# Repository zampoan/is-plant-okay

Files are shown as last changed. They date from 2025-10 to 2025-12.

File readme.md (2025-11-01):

# Is-Plant-Okay 🌱?
## Concept
A solar-powered sensor node that uses a low-power camera and a tiny on-board ML model to detect early signs of plant disease. It will be mounted on a stake and its purpose is to continuously watch the same plant or section of crop bed. 

It will periodically take a picture every 4 hours. When it sees trouble, and will send a compact alert packet over LoRa to a base station. The farmer will receive a notification and can inspect or treat the plant before disease spreads.

Dataset to be trained on: https://www.kaggle.com/datasets/vipoooool/new-plant-diseases-dataset

ML model: https://www.nature.com/articles/s41598-025-06452-5

## Hardware
- 🧠 MCU: Arduino Nano 33 BLE Sense Rev2 
- 🔋 LiIon: 7.4 2000mAh
- ☀️ Solar power cells: 0.5W Solar Panel 55x70
- 📷 Camera: CAMERA-OV7670
- 🌡️ Temperature sensor: Arduino Nano 33 BLE Sense Rev2 (onboard HS3003)
- 🌡️ Humidity sensor: Arduino Nano 33 BLE Sense Rev2 (onboard HS3003)
- ~~🌡️ Soil moisture sensor: (Premi um option: RS485)~~
- 🖵 Screen: GRAPHIC DISPLAY TFT RGB 0.96"
- 📡 LoRa: SX1278 RA-02 (Premium option:RYLR998)
- ~~💡 Light Sensor: TSL2591~~
- ~~⚡ UV Sensor: VEML6075~~

## Software
- KiCad 9.0: Schematic diagram drawing & PCB design
- Fusion 360: Case design

# BOM:
| Hardware | Price ($USD) | QTY| Link |
| :---: | :---: | :--: | :--: |
| Arduino Nano 33 BLE Sense Rev 2 | 38.70 | 1 | https://www.digikey.com.au/en/products/detail/arduino/ABX00069/16891607?s=N4IgTCBcDaIIICEAaAGNA2AnCAugXyA
| 0.5W Solar Panel 55x70 | 6.07 | 2 | https://www.digikey.com.au/en/products/detail/seeed-technology-co-ltd/313070004/5488049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
| CAMERA-OV7670 | 10.25 | 1 | https://www.digikey.com.au/en/products/detail/olimex-ltd/CAMERA-OV7670/21662189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
| (Camera Alternative) Mini 2MP SPI Camera Module | 25.99 | 1 | https://core-electronics.com.au/mini-2mp-spi-camera-module-for-raspberry-pi-pico.html
| GRAPHIC DISPLAY TFT RGB 0.96" | 12.65| 1 | https://www.digikey.com.au/en/products/detail/adafruit-industries-llc/3533/7386265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
| LORA BREAKOUT BOARD WITH ANTENNA (SX1278) | 4.12 | 2 |https://www.digikey.com.au/en/products/detail/ai-thinker/RA-01S-KIT/16688834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
| (Lora alternative) WIO-E5 MINI DEV BRD STM32WLE5JC | 21.90 | 1 | https://www.digikey.com.au/en/products/detail/seeed-technology-co-ltd/113990939/13926228
| 18650 BATTERY PROTECTION MODULE | 3.9 | 1 | https://www.digikey.com.au/en/products/detail/dfrobot/FIT0869/15997370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
| BATT HOLDER 18650 2 CELL PC PIN | 5.16 | 1 | https://www.digikey.com.au/en/products/detail/mpd-memory-protection-devices/BK-18650-PC4/2330513
| SPI RTC | 27.5 | 1 | https://www.digikey.com.au/en/products/detail/sparkfun-electronics/10160/5318743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

## Inspiration
https://blog.arduino.cc/2020/06/24/machine-vision-with-low-cost-camera-modules/
https://cdn-learn.adafruit.com/downloads/pdf/adafruit-mini-tft-0-dot-96-inch-180x60-breakout.pdf
https://files.seeedstudio.com/products/317990687/res/LoRa-E5%20module%20datasheet_V1.0.pdf

# Project Timeline
## Stage 0: Project Conceptualization
Stage 0 focuses on identifying the key skills to develop for this project. My goal was to deepen my understanding of wireless communication and explore how to integrate machine learning into embedded devices. I was particularly interested in how these technologies could support farmers and forest rangers in monitoring crops and plants across large, diverse environment. My goal was to make it as cheap as possible and require little human interaction once placed.

## Stage 1a: Development board stage
Stage 1a involves selecting different components to interface with each other. The most important element was the microcontroller, and I choose the Arduino Nano 33 BLE Sense V2 for its built in sensor capabilities, community support and access to TF-lite as an edge-ml solution.

The next was selecting a camera, I needed a camera that I could use off the shelf quickly for developing. Originally HM0360-MWA-00FP963 was selected, but I found it difficult to find a dev board for it. So the OV7670 was selected instead.

Similiar to the camera, SX1278 RA-02 module was selected because a dev board was available, and the DS3234 was chosen because SPI is the common protocol that is being used.

## Stage 1b: Developing the model
The model that is being used is based of the paper: [AI and IoT-powered edge device optimized for crop pest and disease detection](https://www.nature.com/articles/s41598-025-06452-5) and is called Tiny-LiteNet. It was chosen because of its use case matched  and identifiable metrics used to train and test the model. 

The model is made from scratch and is trained on a different dataset and uses a pretrained MobileNetv2 model as a teacher model. Tiny-LiteNet utilises six squeeze-and-excitation (SE) depthwise blocks to enhance feature representation, reduce compute cost and improve accuracy combined. The size of this model is 1.2Mb.

Tiny-LiteNet architecture:
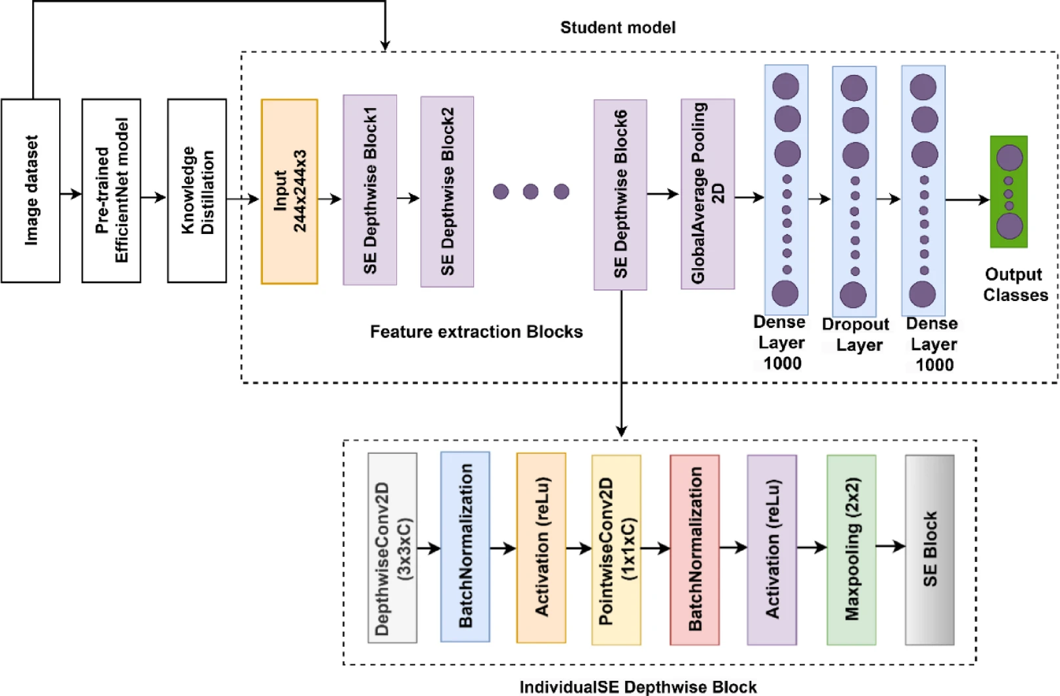
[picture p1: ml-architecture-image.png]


## Stage 2a: PCB design

## Stage 2b: CAD design

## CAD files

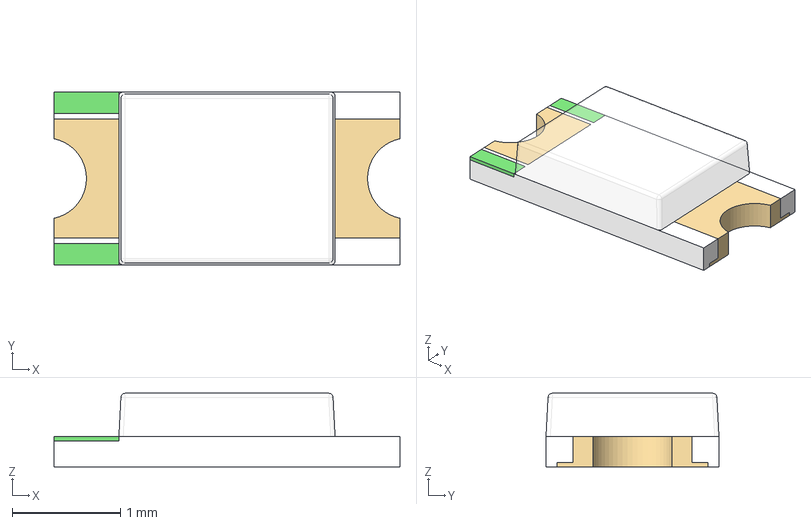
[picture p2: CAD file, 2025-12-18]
ELECTRICAL/is-plant-okay/KICAD_PROJECT_LIBRARY/150120GS75000_/WL-SMCW_1206.step
3.20 x 1.60 x 0.68 mm
marking x 2
housing
cover
base x 2

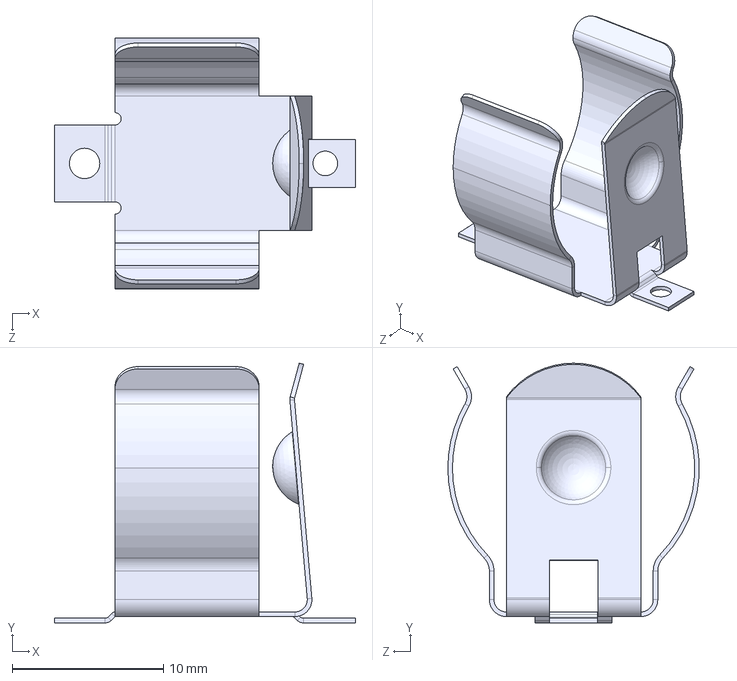
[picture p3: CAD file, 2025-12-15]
ELECTRICAL/is-plant-okay/KICAD_PROJECT_LIBRARY/254TR-2/254TR.step
19.9 x 17.2 x 16.6 mm

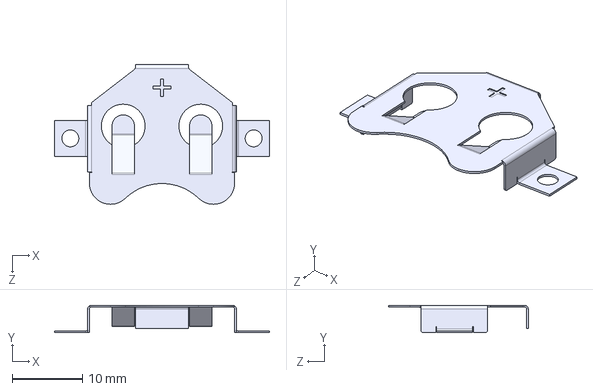
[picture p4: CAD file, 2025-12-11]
ELECTRICAL/is-plant-okay/KICAD_PROJECT_LIBRARY/BAT_HLD_003_SMT/BAT-HLD-003-SMT.step
30.5 x 3.90 x 19.8 mm

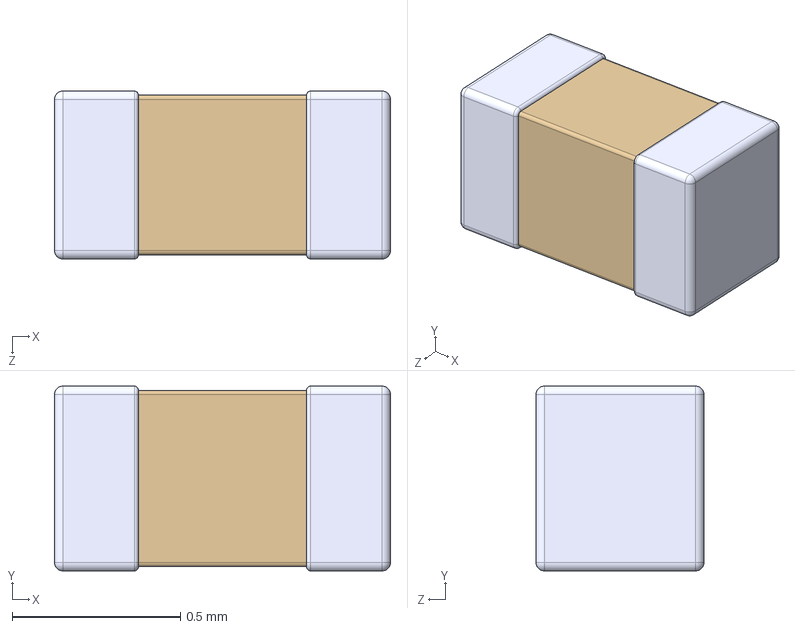
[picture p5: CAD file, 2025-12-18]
ELECTRICAL/is-plant-okay/KICAD_PROJECT_LIBRARY/CL05B104KO5NNNC/CL05B104KO5NNNC.step
1.00 x 0.55 x 0.5 mm

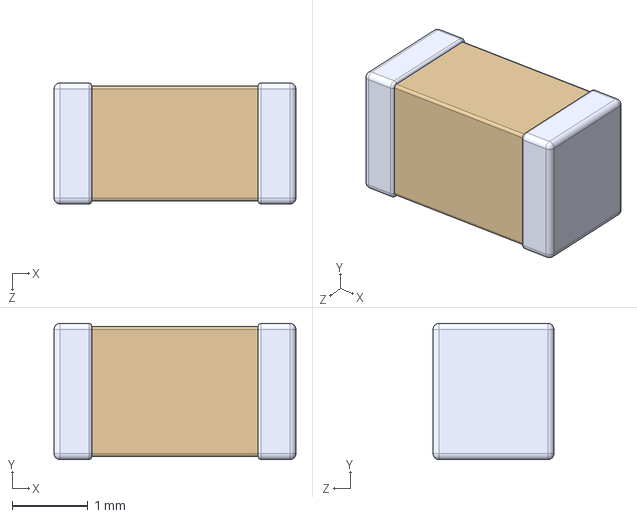
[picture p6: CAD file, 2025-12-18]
ELECTRICAL/is-plant-okay/KICAD_PROJECT_LIBRARY/CL31B105KBHNNNE/CL31B105KBHNNNE.step
3.20 x 1.80 x 1.60 mm

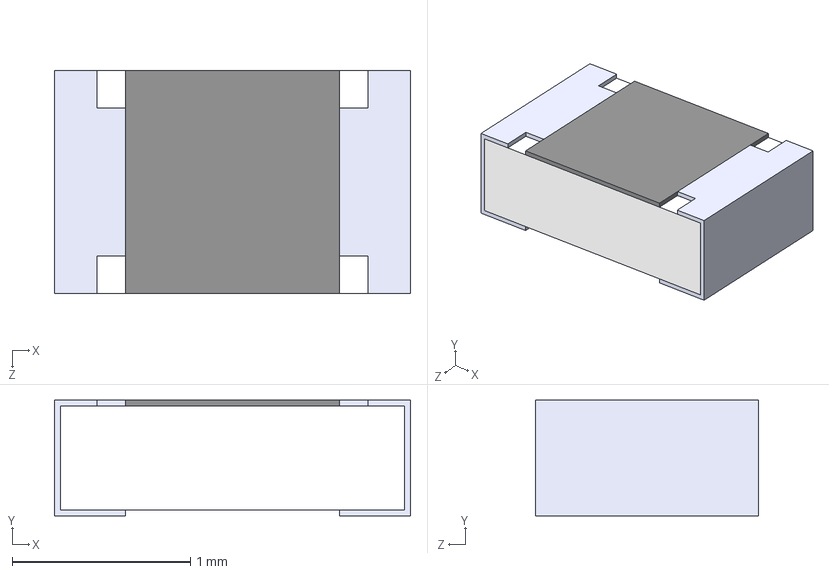
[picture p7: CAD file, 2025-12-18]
ELECTRICAL/is-plant-okay/KICAD_PROJECT_LIBRARY/CRGCQ0805J470R/CRGCQ0805J470R.step
2.00 x 0.65 x 1.25 mm

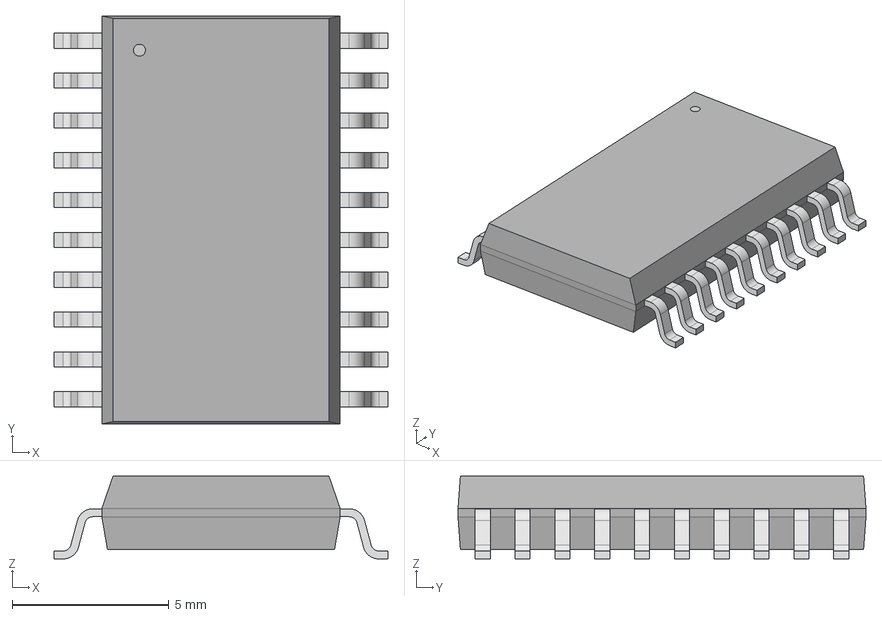
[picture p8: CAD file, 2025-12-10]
ELECTRICAL/is-plant-okay/KICAD_PROJECT_LIBRARY/DS3234S_T_R/21-0042O_W20H2_MXM.step
10.6 x 13.0 x 2.64 mm

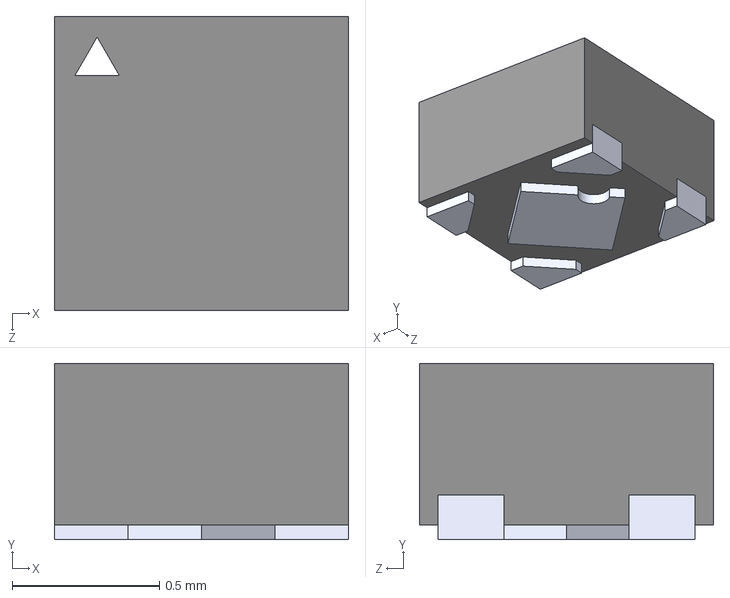
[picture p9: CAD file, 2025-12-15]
ELECTRICAL/is-plant-okay/KICAD_PROJECT_LIBRARY/MIC5365_3_3YMT_TZ/MIC5365-3.3YMT-TZ.step
1.00 x 0.6 x 1.00 mm

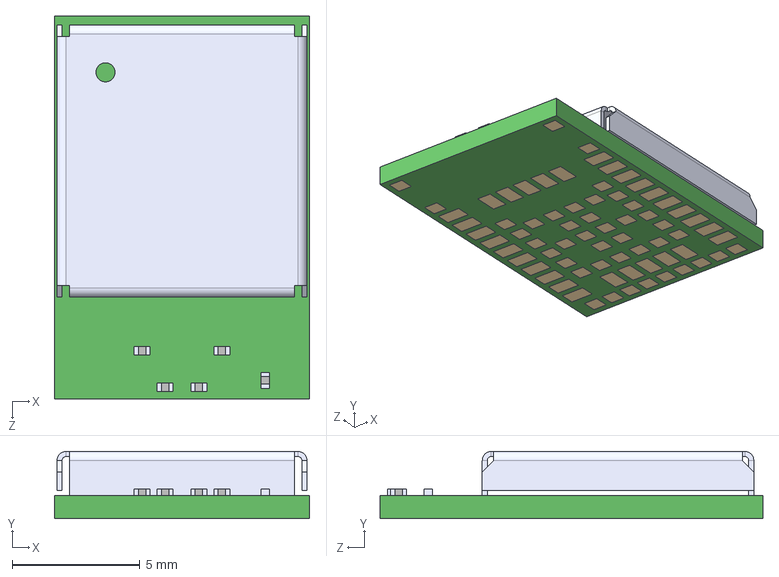
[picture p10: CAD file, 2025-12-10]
ELECTRICAL/is-plant-okay/KICAD_PROJECT_LIBRARY/NINA_B306_00B/NINA-B306-00B.step
10.0 x 2.63 x 15.0 mm

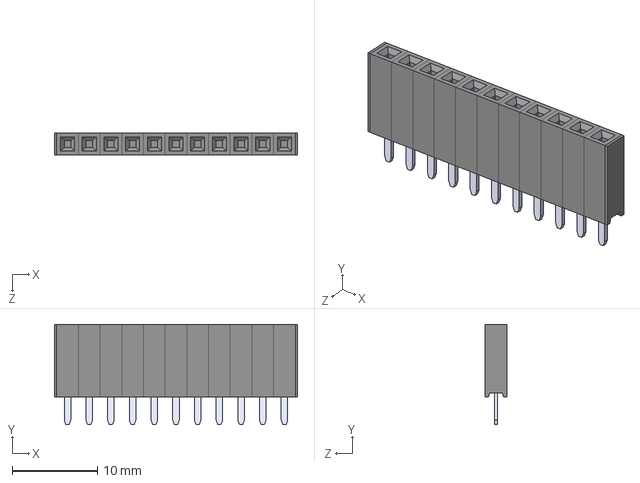
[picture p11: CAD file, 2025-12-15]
ELECTRICAL/is-plant-okay/KICAD_PROJECT_LIBRARY/PPTC111LFBN-RC/PPTC111LFBN-RC.STEP
28.4 x 11.7 x 2.54 mm
PPPC021LFBN-RC_C11
Pin - Tin x 11

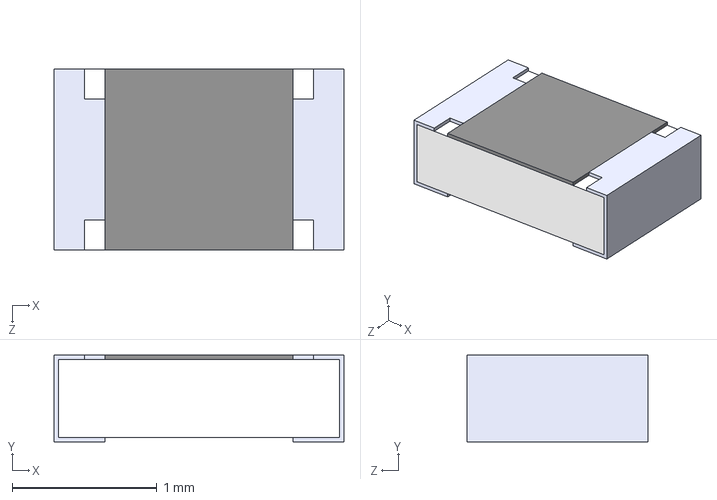
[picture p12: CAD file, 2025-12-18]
ELECTRICAL/is-plant-okay/KICAD_PROJECT_LIBRARY/RC0805FR_7W10KL/RC0805FR-7W10KL.step
2.00 x 0.6 x 1.25 mm

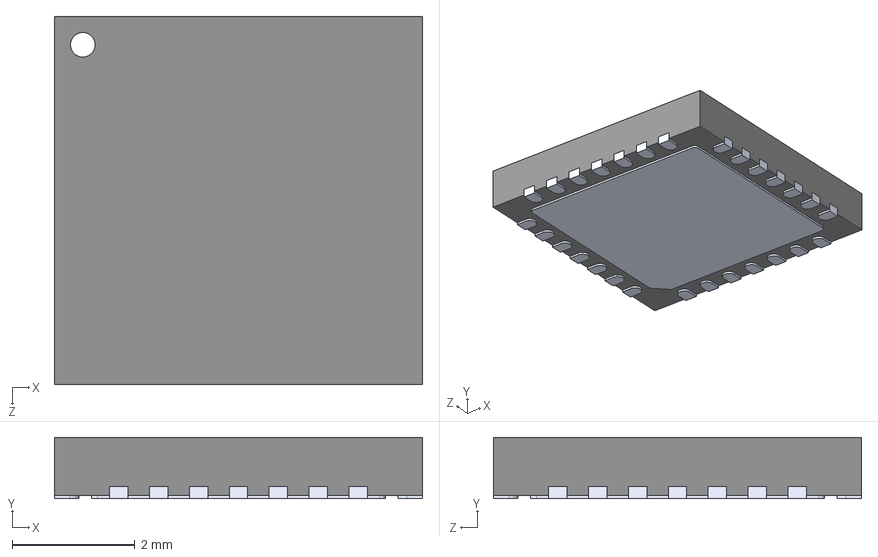
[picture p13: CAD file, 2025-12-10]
ELECTRICAL/is-plant-okay/KICAD_PROJECT_LIBRARY/SX1276IMLTRT/SX1276IMLTRT.step
6.00 x 1.00 x 6.00 mm

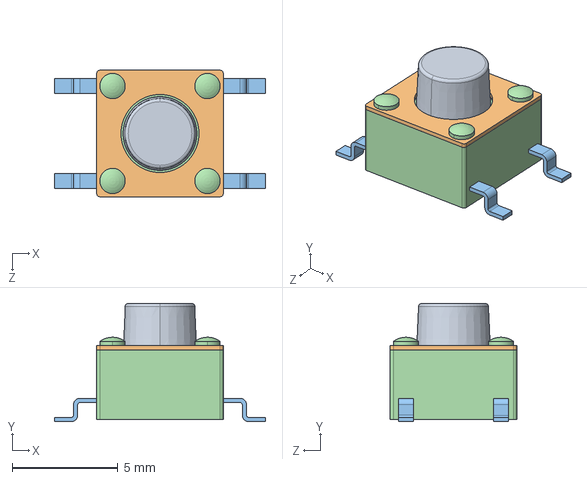
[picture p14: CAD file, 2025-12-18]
ELECTRICAL/is-plant-okay/KICAD_PROJECT_LIBRARY/TS04_66_55_BK_260_SMT/TS04-66-55-BK-260-SMT.STEP
10.0 x 5.60 x 6.00 mm

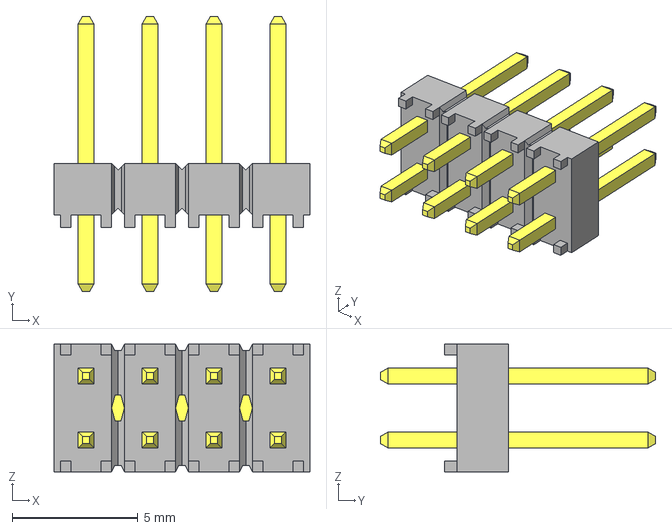
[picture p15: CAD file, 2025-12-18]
ELECTRICAL/is-plant-okay/KICAD_PROJECT_LIBRARY/TSW_104_07_F_D/TSW-104-07-F-D.stp
10.2 x 10.9 x 5.08 mm
TSW-104-07-F-D_body
T-1S6-07-TSW-1-07-4-D

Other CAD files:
ELECTRICAL/is-plant-okay/KICAD_PROJECT_LIBRARY/RC0805JR_075K1L/RC0805JR-075K1L.step
ELECTRICAL/is-plant-okay/KICAD_PROJECT_LIBRARY/UJ20_C_H_G_SMT_5_P16_TR/UJ20-C-H-G-SMT-5-P16-TR.step
ELECTRICAL/is-plant-okay/KICAD_PROJECT_LIBRARY/USB4085_GF_A/USB4085-GF-A.STEP
ELECTRICAL/is-plant-okay/KICAD_PROJECT_LIBRARY/USBLC6_2SC6-2/USBLC6-2SC6.step
ELECTRICAL/is-plant-okay/KICAD_PROJECT_LIBRARY/10129381_918001BLF/10129381-918001BLF.step
ELECTRICAL/is-plant-okay/KICAD_PROJECT_LIBRARY/BQ24650RVAT/BQ24650RVAT.step
ELECTRICAL/is-plant-okay/KICAD_PROJECT_LIBRARY/BQ7791504PW/BQ7791504PW.step
ELECTRICAL/is-plant-okay/KICAD_PROJECT_LIBRARY/MCP73871_2CCI_ML/MCP73871-2CCI_ML.step
ELECTRICAL/is-plant-okay/KICAD_PROJECT_LIBRARY/Wio-SX1262 Module Kicad Library/Wio-SX1262 file.step
ELECTRICAL/is-plant-okay/KICAD_PROJECT_LIBRARY/ZOR_25_B_52_0R/RES_ZOR25_6P3X2P3_YAG.step

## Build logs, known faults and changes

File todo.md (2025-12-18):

# Todo list
## Stage 1a
 - Put together hardware
 - Code software to interface w/ hardware
## Stage 1b
- Test and deploy model
- Build pipeline?
## Stage 2a
- Make Rev 1 of PCB
Complete schematics for the following:
    - MCU
    - ~~DISPLAY_TFT~~
    - ~~RTC_DS3234~~
    - ~~CAMERA~~    
    - ~~LoRA~~
    - ~~USB_C~~
    - ~~MCP78371~~

- Check if GPIO is default High impedance from the registers

Find out if below is possible:
| Goal | Best Option | 
| :---: | :---: |
| Want to run Arduino sketches | Flash Arduino Nano BLE bootloader |
| Want to run Python scripts | Use Adafruit UF2 bootloader + CircuitPython| 
| Want full control / Zephyr / SDK | Use Nordic’s SDK + J-Link |
| Want both Arduino + MicroPython flexibility| Use Adafruit UF2 bootloader, supports both|

- learn to write over the bootloader, flash from scratch

## Stage 2b
- Design model housing

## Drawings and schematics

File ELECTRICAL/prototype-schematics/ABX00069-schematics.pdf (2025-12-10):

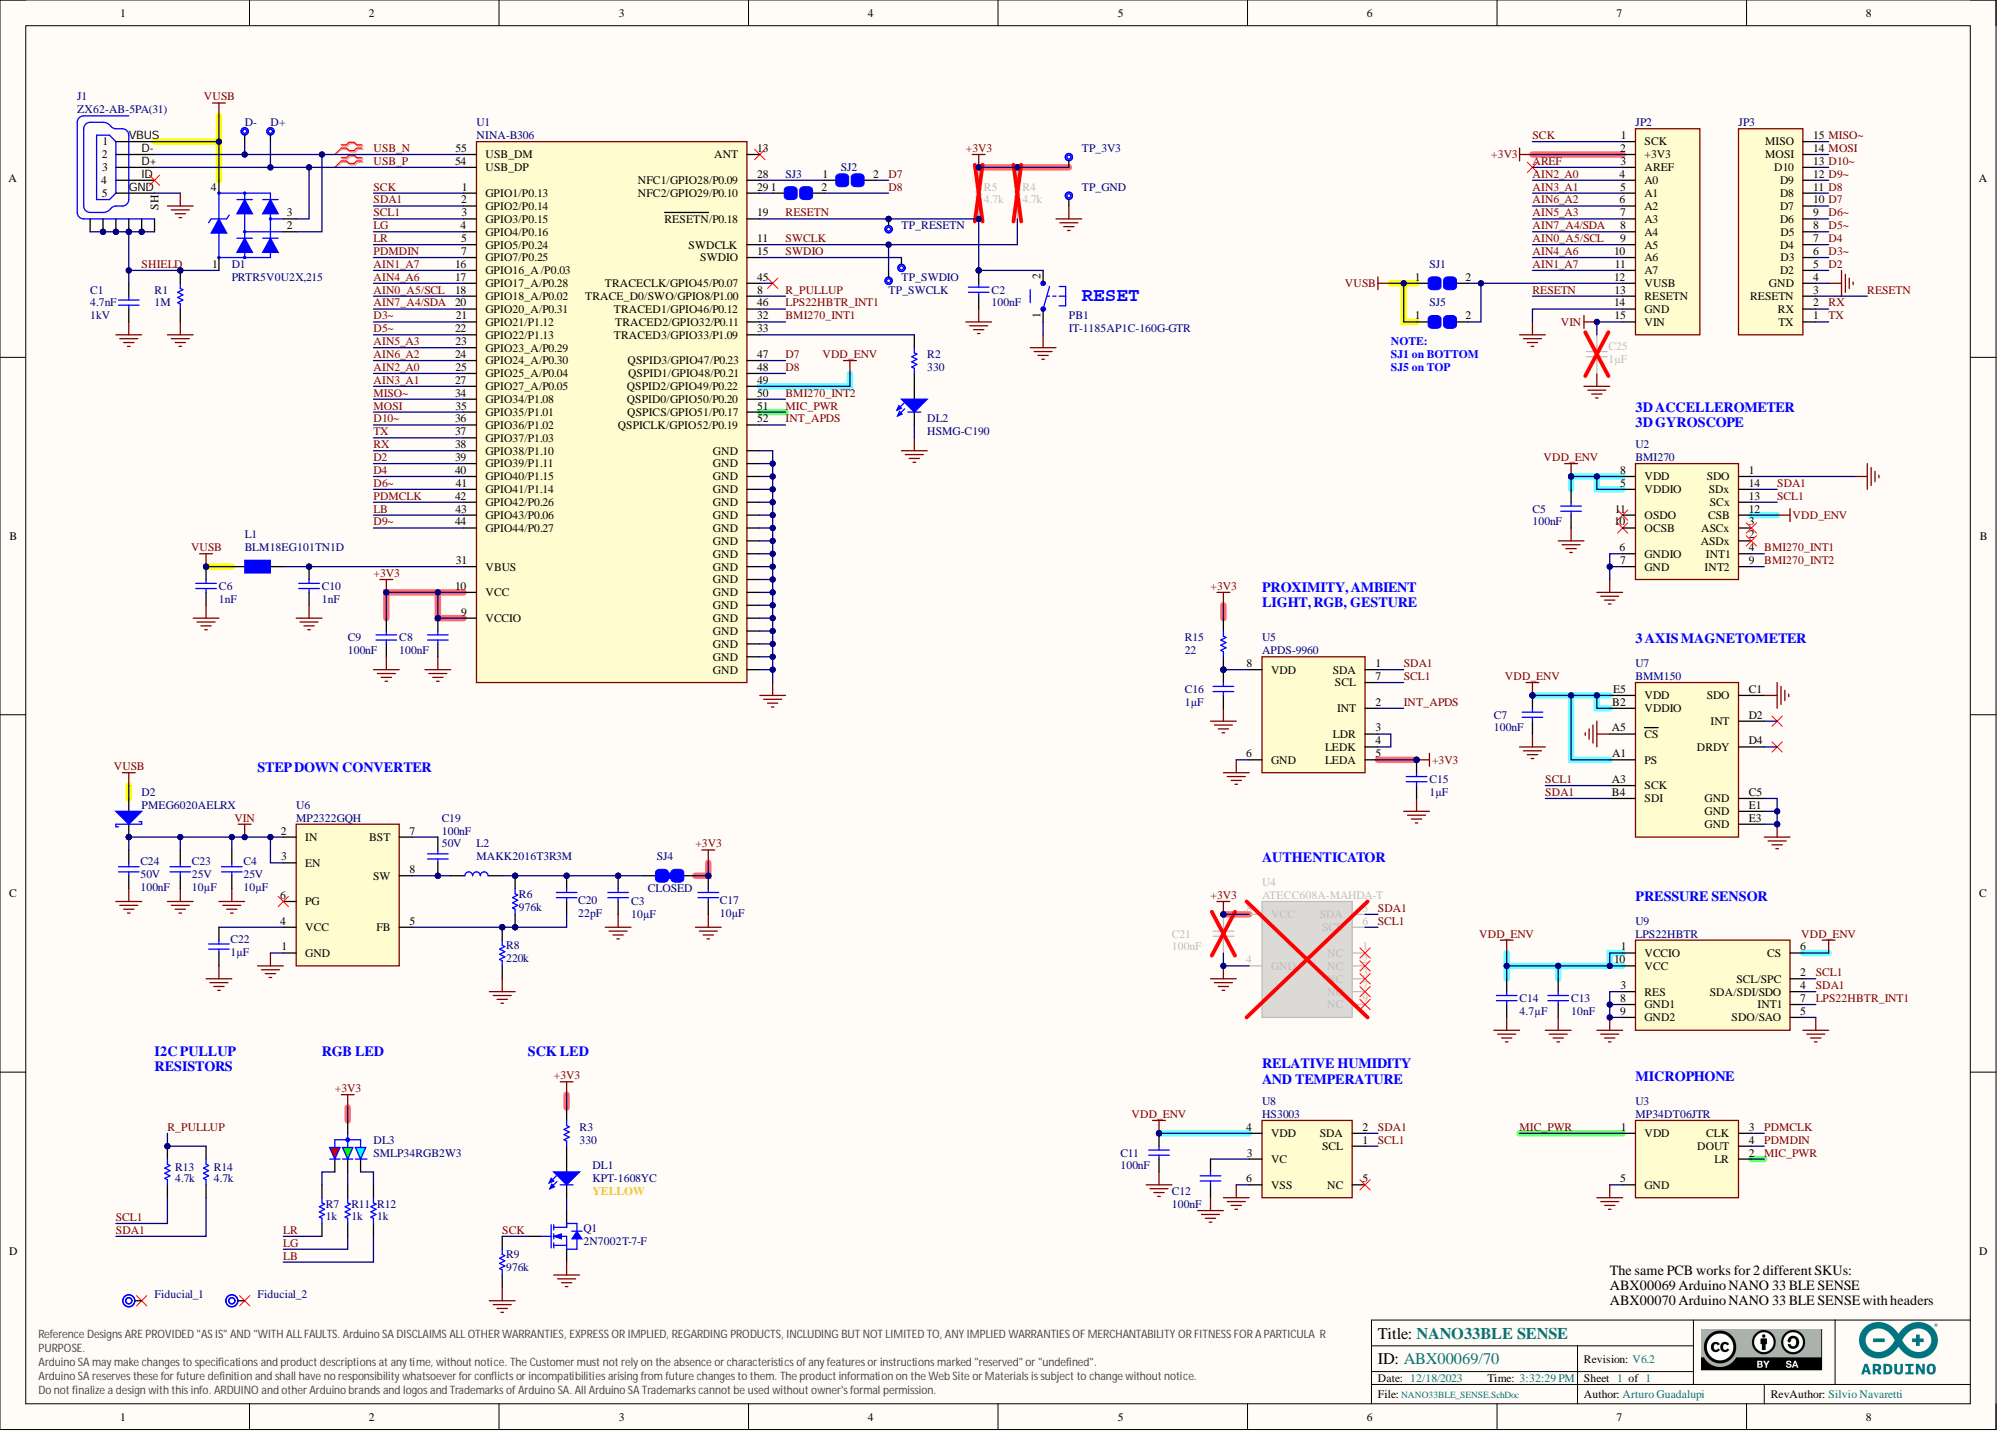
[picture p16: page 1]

E 1
E 3

Reference Designs ARE PROVI
PURPOSE.
Arduino SA may ma
Arduino SA reserves these for future definition and shall have no responsibility whatsoever for conflicts or incompatibiliti

DED "AS IS" AND "WITH ALL FAULTS. Arduino SA DISCLAIMS ALL OTHER WARRANTIES, EXPRESS OR IMPLIED, REGARDING PRODUCTS, INCLUDING BUT NOT LIMITED TO, ANY IMPLIED WARRANTIES OF MERCHANTABI

ke changes to specifi

tions and product descriptions at a

ce. The Customer must not rely on the absence or cha

ny features or instructions ma

rked "reserved" or "undefined".

rising from future changes to them. The product informa

tion on the Web Site or Materials is subject to change without noti

Do not finalize a design with this info. ARDUINO and other Arduino brands and logos and Tradema

rks of Arduino SA. All Arduino SA Tradema

rks cannot be used without owner's formal permission.

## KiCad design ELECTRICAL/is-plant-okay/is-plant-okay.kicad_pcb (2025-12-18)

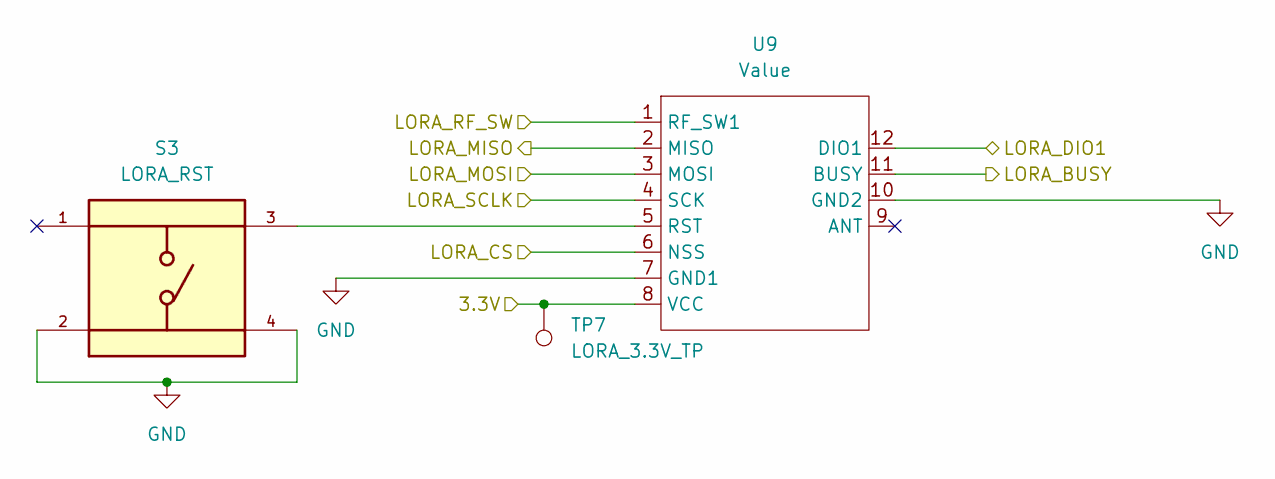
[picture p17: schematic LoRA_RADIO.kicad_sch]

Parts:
S3: LORA_RST; SW_TS04-66-55-BK-260-SMT; MFG PART # TS04-66-55-BK-260-SMT
TP7: LORA_3.3V_TP; TestPoint_Keystone_5000-5004_Miniature
U9: Value; Wio-SX1262 PCB Package; MFG PART # 114993390

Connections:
/3.3V: TP7.1, U9.8 (VCC); also elsewhere on the board
/LORA_BUSY: U9.11 (BUSY); also elsewhere on the board
/LORA_CS: U9.6 (NSS); also elsewhere on the board
/LORA_DIO1: U9.12 (DIO1); also elsewhere on the board
/LORA_MISO: U9.2 (MISO); also elsewhere on the board
/LORA_MOSI: U9.3 (MOSI); also elsewhere on the board
/LORA_RF_SW: U9.1 (RF_SW1); also elsewhere on the board
/LORA_SCLK: U9.4 (SCK); also elsewhere on the board
GND: S3.2, S3.4, U9.7 (GND1), U9.10 (GND2); also elsewhere on the board
unnamed: S3.3, U9.5 (RST)

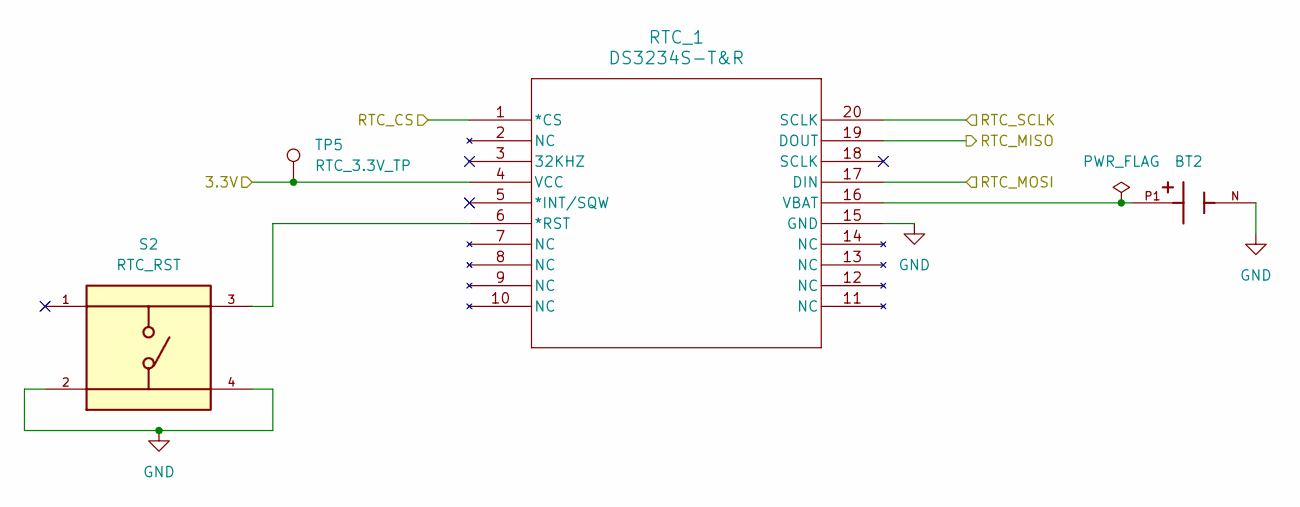
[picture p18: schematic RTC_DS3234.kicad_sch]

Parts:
BT2: BAT-HLD-003-SMT; BAT_BAT-HLD-003-SMT; MFG PART # BAT-HLD-003-SMT
RTC_1: DS3234S-T&R; 21-0042O_W20-H2_MXM-L; MFG PART # DS3234S#
S2: RTC_RST; SW_TS04-66-55-BK-260-SMT; MFG PART # TS04-66-55-BK-260-SMT
TP5: RTC_3.3V_TP; TestPoint_Keystone_5000-5004_Miniature

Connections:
/3.3V: RTC_1.4 (VCC), TP5.1; also elsewhere on the board
/LORA_MISO: RTC_1.19 (DOUT); also elsewhere on the board
/LORA_MOSI: RTC_1.17 (DIN); also elsewhere on the board
/LORA_SCLK: RTC_1.20 (SCLK); also elsewhere on the board
/RTC_CS: RTC_1.1 (*CS); also elsewhere on the board
GND: BT2.N, RTC_1.15 (GND), S2.2, S2.4; also elsewhere on the board
unnamed: RTC_1.6 (*RST), S2.3
unnamed: BT2.P1, RTC_1.16 (VBAT)

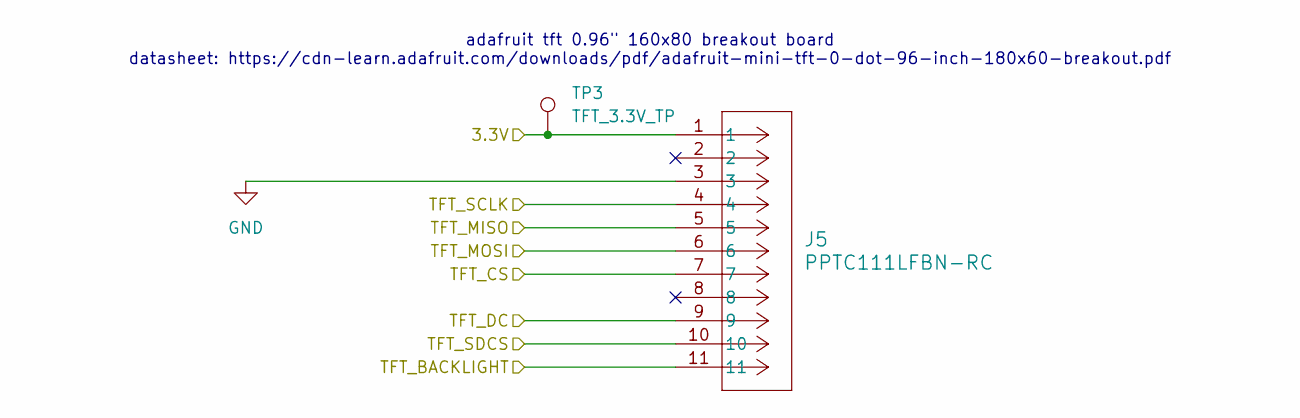
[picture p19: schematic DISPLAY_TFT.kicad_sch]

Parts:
J5: PPTC111LFBN-RC; CONN11_PPPN111_SUL; MFG PART # PPTC111LFBN-RC
TP3: TFT_3.3V_TP; TestPoint_Keystone_5000-5004_Miniature

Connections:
/3.3V: J5.1, TP3.1; also elsewhere on the board
/BACKLIGHT: J5.11; also elsewhere on the board
/LORA_MISO: J5.5; also elsewhere on the board
/LORA_MOSI: J5.6; also elsewhere on the board
/LORA_SCLK: J5.4; also elsewhere on the board
/TFT_CS: J5.7; also elsewhere on the board
/TFT_DC: J5.9; also elsewhere on the board
/TFT_SDCS: J5.10; also elsewhere on the board
GND: J5.3; also elsewhere on the board

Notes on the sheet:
adafruit tft 0.96" 160x80 breakout board datasheet: https://cdn-learn.adafruit.com/downloads/pdf/adafruit-mini-tft-0-dot-96-inch-180x60-breakout.pdf

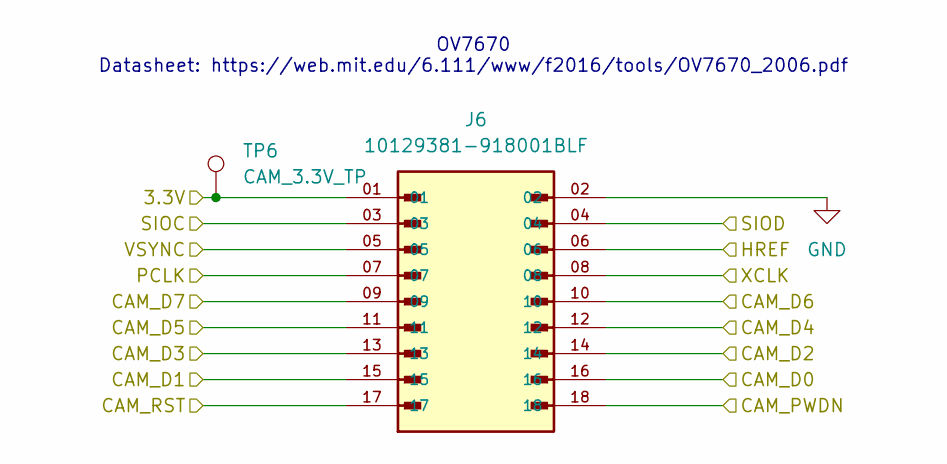
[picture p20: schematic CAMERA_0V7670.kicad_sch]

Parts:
J6: 10129381-918001BLF; AMPHENOL_10129381-918001BLF; MFG PART # 10129381-918001BLF
TP6: CAM_3.3V_TP; TestPoint_Keystone_5000-5004_Miniature

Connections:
/3.3V: J6.01, TP6.1; also elsewhere on the board
/CAM_D0: J6.16; also elsewhere on the board
/CAM_D1: J6.15; also elsewhere on the board
/CAM_D2: J6.14; also elsewhere on the board
/CAM_D3: J6.13; also elsewhere on the board
/CAM_D4: J6.12; also elsewhere on the board
/CAM_D5: J6.11; also elsewhere on the board
/CAM_D6: J6.10; also elsewhere on the board
/CAM_D7: J6.09; also elsewhere on the board
/CAM_PWDN: J6.18; also elsewhere on the board
/CAM_RST: J6.17; also elsewhere on the board
/HREF: J6.06; also elsewhere on the board
/PCLK: J6.07; also elsewhere on the board
/SIOC: J6.03; also elsewhere on the board
/SIOD: J6.04; also elsewhere on the board
/VSYNC: J6.05; also elsewhere on the board
/XCLK: J6.08; also elsewhere on the board
GND: J6.02; also elsewhere on the board

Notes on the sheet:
OV7670 Datasheet: https://web.mit.edu/6.111/www/f2016/tools/OV7670_2006.pdf

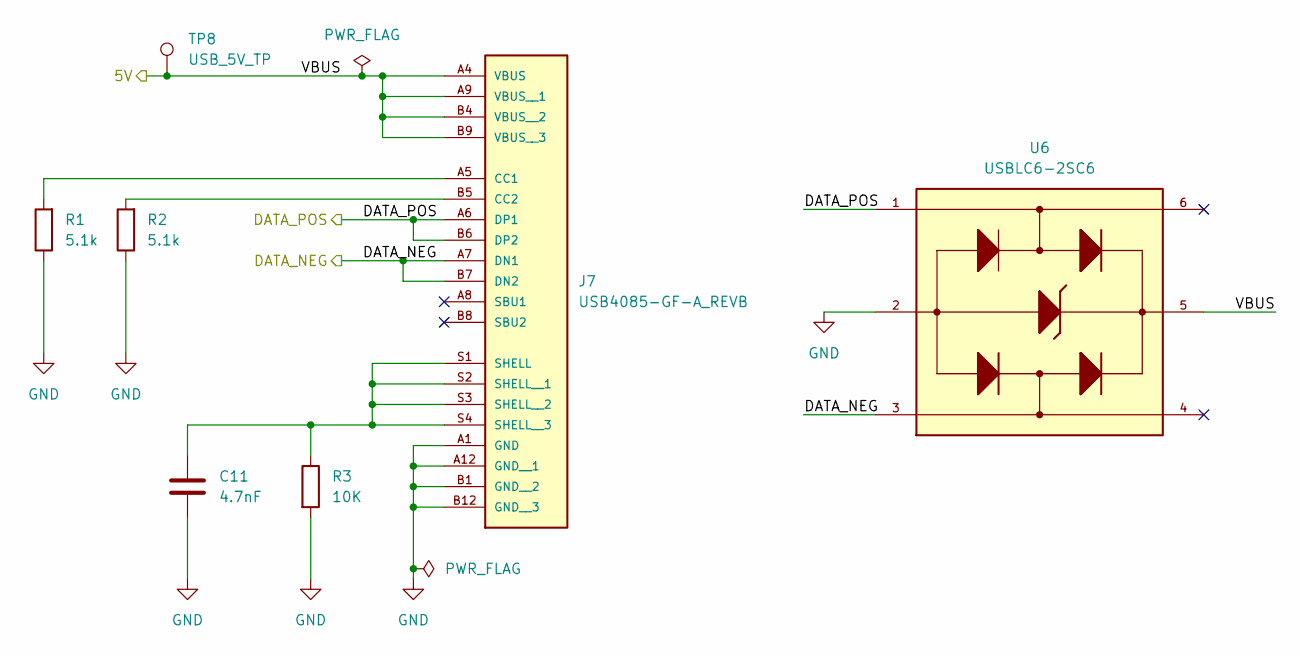
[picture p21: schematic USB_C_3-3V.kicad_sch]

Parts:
C11: 4.7nF; CAPC1005X55N; MFG PART # CL05B104KO5NNNC
J7: USB4085-GF-A_REVB; GCT_USB4085-GF-A_REVB; MFG PART # USB4085-GF-A
R1, R2: 5.1k; RC0805JR-075K1L; MFG PART # RC0805JR-075K1L
R3: 10K; RC0805FR-7W10KL; MFG PART # RC0805FR-7W10KL
TP8: USB_5V_TP; TestPoint_Keystone_5000-5004_Miniature
U6: USBLC6-2SC6; SOT95P280X145-6N; MFG PART # USBLC6-2SC6

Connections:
/5V: J7.A4 (VBUS), J7.A9 (VBUS__1), J7.B4 (VBUS__2), J7.B9 (VBUS__3), TP8.1, U6.5; also elsewhere on the board
/DATA_NEG: J7.A7 (DN1), J7.B7 (DN2), U6.3; also elsewhere on the board
/DATA_POS: J7.A6 (DP1), J7.B6 (DP2), U6.1; also elsewhere on the board
GND: C11.2, J7.A1 (GND), J7.A12 (GND__1), J7.B1 (GND__2), J7.B12 (GND__3), R1.1, R2.1, R3.2, U6.2; also elsewhere on the board
unnamed: J7.A5 (CC1), R1.2
unnamed: J7.B5 (CC2), R2.2
unnamed: C11.1, J7.S1 (SHELL), J7.S2 (SHELL__1), J7.S3 (SHELL__2), J7.S4 (SHELL__3), R3.1

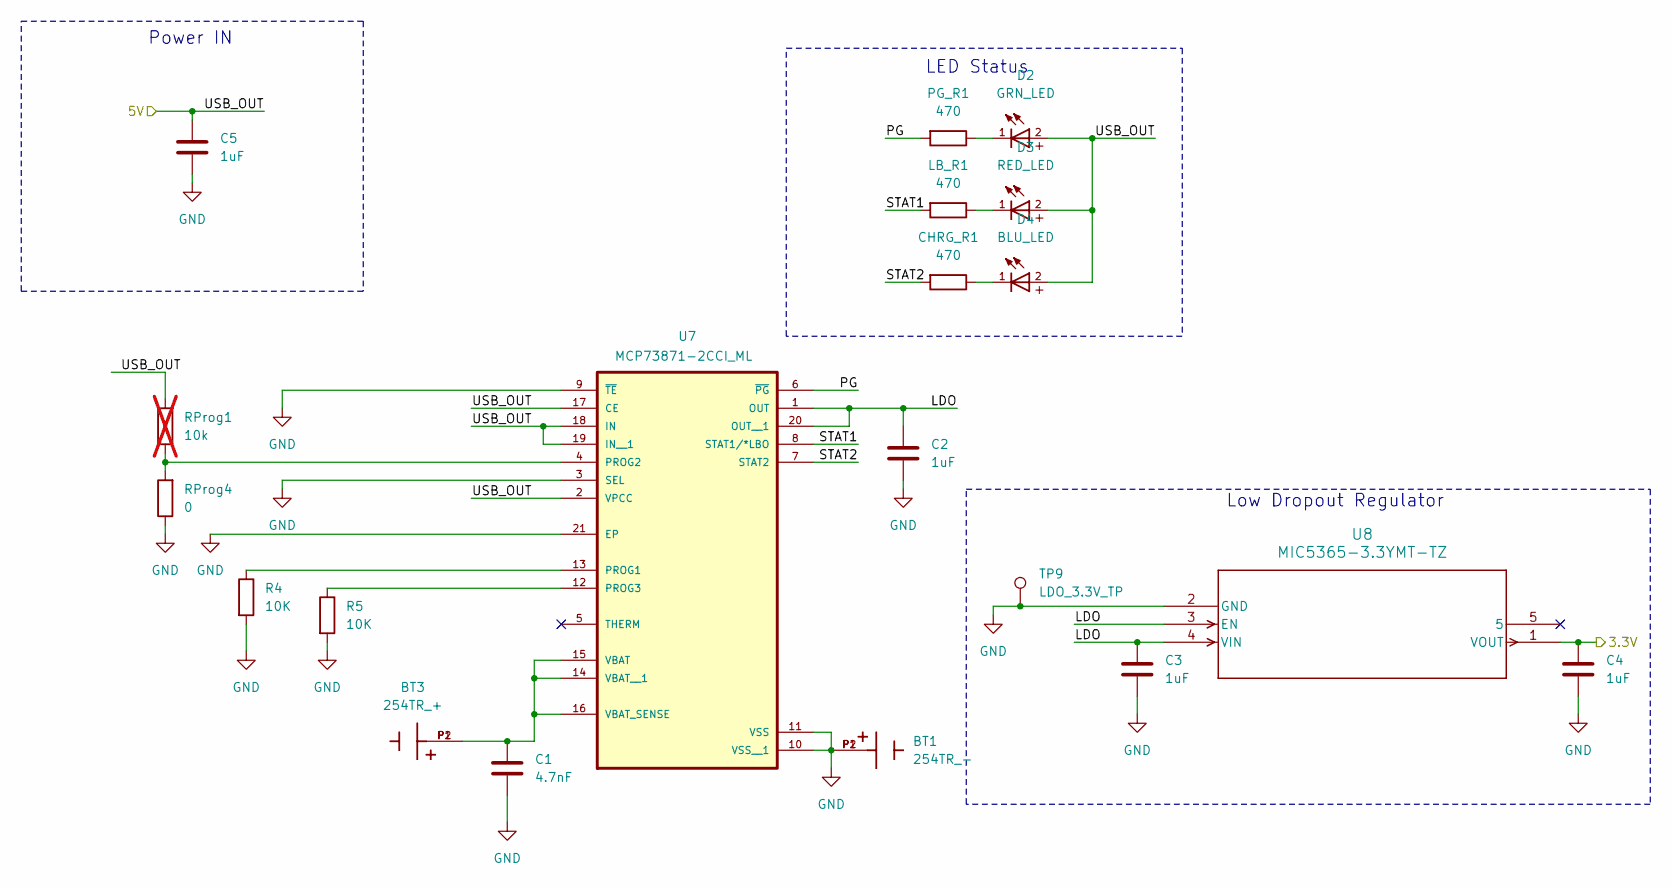
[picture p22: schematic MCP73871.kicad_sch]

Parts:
BT1: 254TR_-; BAT_254TR; MFG PART # 254TR
BT3: 254TR_+; BAT_254TR; MFG PART # 254TR
C1: 4.7nF; CAPC1005X55N; MFG PART # CL05B104KO5NNNC
C2, C3, C4, C5: 1uF; CAPC3216X180N; MFG PART # CL31B105KBHNNNE
CHRG_R1: 470; RESC2012X65N
D2: GRN_LED; 150120GS75000; MFG PART # 150120GS75000
D3: RED_LED; 150120GS75000; MFG PART # 150120RS75000
D4: BLU_LED; 150120GS75000; MFG PART # 150120BS75000
LB_R1: 470; RESC2012X65N
PG_R1: 470; RESC2012X65N
R4, R5: 10K; RC0805FR-7W10KL; MFG PART # RC0805FR-7W10KL
RProg1: 10k; RES_ZOR25_6P3X2P3_YAG; MFG PART # ZOR-25-B-52-0R; not fitted
RProg4: 0; RES_ZOR25_6P3X2P3_YAG; MFG PART # ZOR-25-B-52-0R
TP9: LDO_3.3V_TP; TestPoint_Keystone_5000-5004_Miniature
U7: MCP73871-2CCI_ML; QFN50P400X400X100-21N; MFG PART # MCP73871-2CCI/ML
U8: MIC5365-3.3YMT-TZ; TMLF-4_MCH; MFG PART # MIC5365-3.3YMT-TZ

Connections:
/3.3V: C4.1, U8.1 (VOUT); also elsewhere on the board
/5V: C5.1, D2.2, D3.2, D4.2, RProg1.2, U7.2 (VPCC), U7.17 (CE), U7.18 (IN), U7.19 (IN__1); also elsewhere on the board
/MCP73871/LDO: C2.1, C3.1, U7.1 (OUT), U7.20 (OUT__1), U8.3 (EN), U8.4 (VIN)
/MCP73871/PG: PG_R1.2, U7.6 (~PG)
/MCP73871/STAT1: LB_R1.2, U7.8 (STAT1/*LBO)
/MCP73871/STAT2: CHRG_R1.2, U7.7 (STAT2)
GND: BT1.P1, BT1.P2, C1.2, C2.2, C3.2, C4.2, C5.2, R4.2, R5.2, RProg4.1, TP9.1, U7.3 (SEL), U7.9 (~TE), U7.10 (VSS__1), U7.11 (VSS), U7.21 (EP), U8.2 (GND); also elsewhere on the board
unnamed: CHRG_R1.1, D4.1
unnamed: D2.1, PG_R1.1
unnamed: D3.1, LB_R1.1
unnamed: R4.1, U7.13 (PROG1)
unnamed: RProg1.1, RProg4.2, U7.4 (PROG2)
unnamed: R5.1, U7.12 (PROG3)
unnamed: BT3.P1, BT3.P2, C1.1, U7.14 (VBAT__1), U7.15 (VBAT), U7.16 (VBAT_SENSE)

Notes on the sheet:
Low Dropout Regulator
LED Status
Power IN

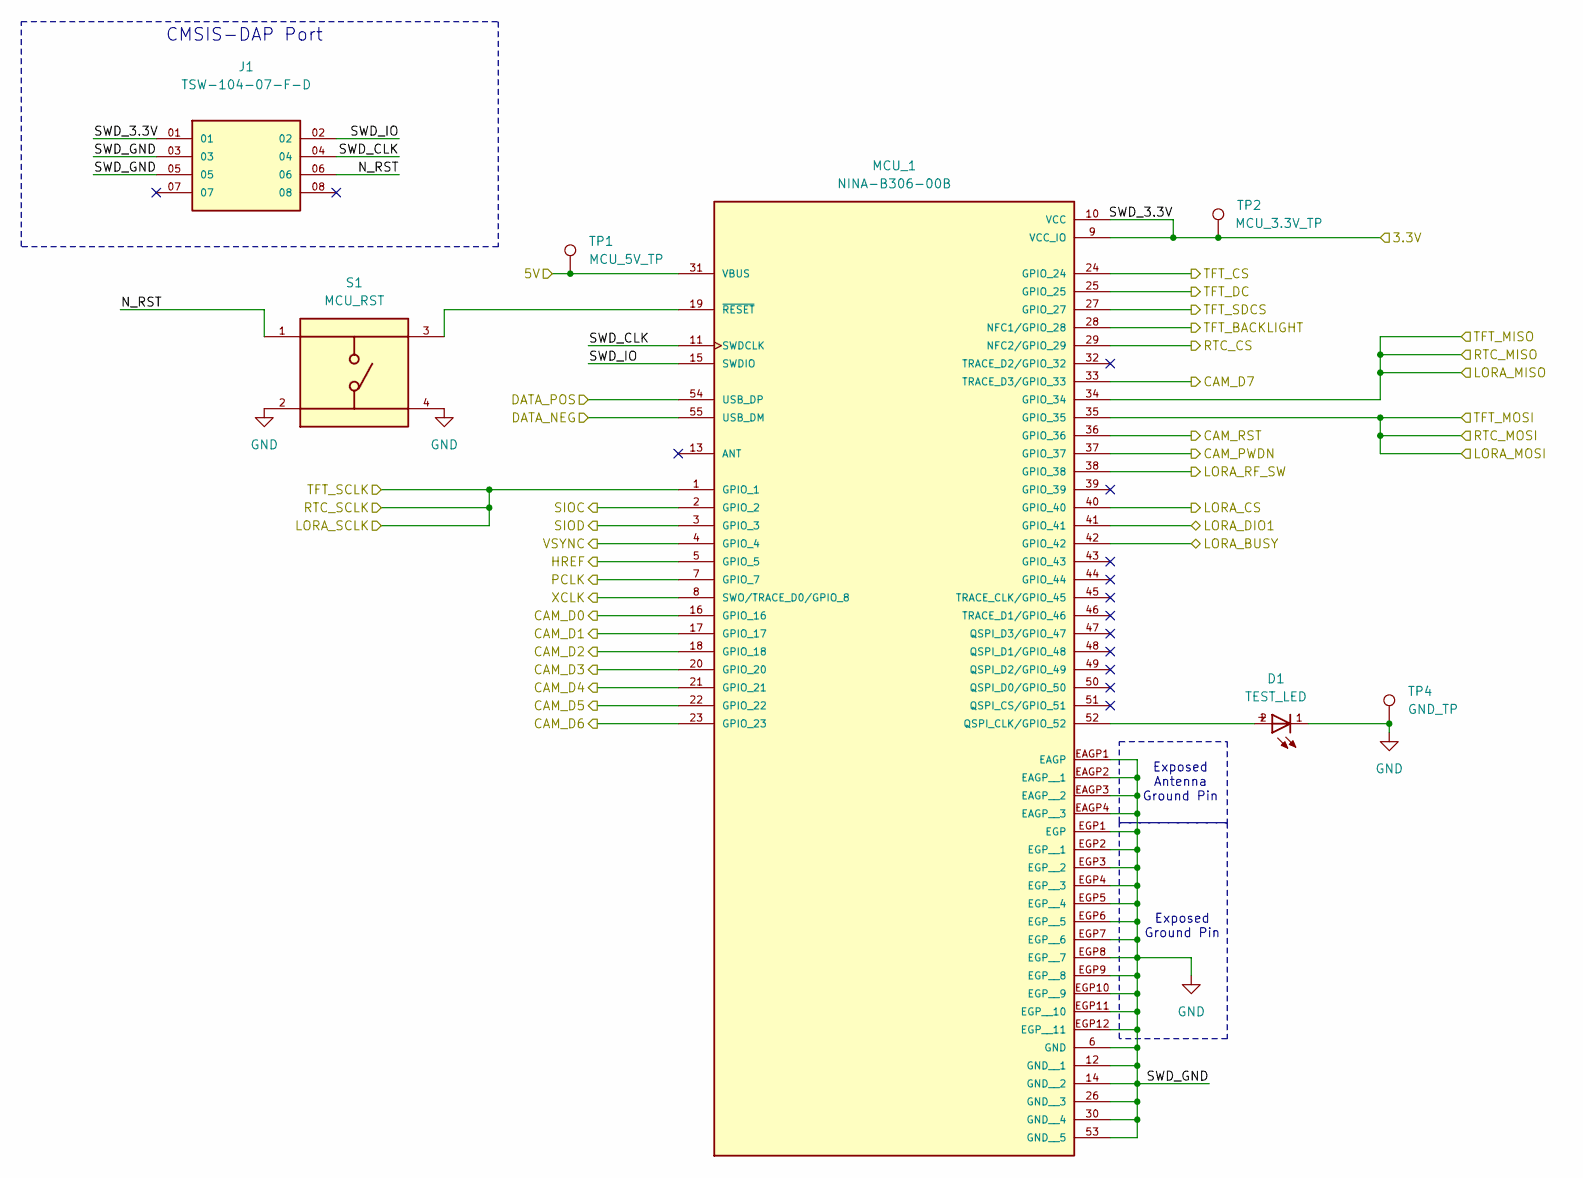
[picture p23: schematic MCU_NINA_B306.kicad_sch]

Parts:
D1: TEST_LED; 150120GS75000; MFG PART # 150120GS75000
J1: TSW-104-07-F-D; SAMTEC_TSW-104-07-F-D
MCU_1: NINA-B306-00B; XCVR_NINA-B306-00B; MFG PART # NINA-B306-01B
S1: MCU_RST; SW_TS04-66-55-BK-260-SMT; MFG PART # TS04-66-55-BK-260-SMT
TP1: MCU_5V_TP; TestPoint_Keystone_5000-5004_Miniature
TP2: MCU_3.3V_TP; TestPoint_Keystone_5000-5004_Miniature
TP4: GND_TP; TestPoint_Keystone_5000-5004_Miniature

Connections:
/3.3V: J1.01, MCU_1.9 (VCC_IO), MCU_1.10 (VCC), TP2.1; also elsewhere on the board
/5V: MCU_1.31 (VBUS), TP1.1; also elsewhere on the board
/BACKLIGHT: MCU_1.28 (NFC1/GPIO_28); also elsewhere on the board
/CAM_D0: MCU_1.16 (GPIO_16); also elsewhere on the board
/CAM_D1: MCU_1.17 (GPIO_17); also elsewhere on the board
/CAM_D2: MCU_1.18 (GPIO_18); also elsewhere on the board
/CAM_D3: MCU_1.20 (GPIO_20); also elsewhere on the board
/CAM_D4: MCU_1.21 (GPIO_21); also elsewhere on the board
/CAM_D5: MCU_1.22 (GPIO_22); also elsewhere on the board
/CAM_D6: MCU_1.23 (GPIO_23); also elsewhere on the board
/CAM_D7: MCU_1.33 (TRACE_D3/GPIO_33); also elsewhere on the board
/CAM_PWDN: MCU_1.37 (GPIO_37); also elsewhere on the board
/CAM_RST: MCU_1.36 (GPIO_36); also elsewhere on the board
/DATA_NEG: MCU_1.55 (USB_DM); also elsewhere on the board
/DATA_POS: MCU_1.54 (USB_DP); also elsewhere on the board
/HREF: MCU_1.5 (GPIO_5); also elsewhere on the board
/LORA_BUSY: MCU_1.42 (GPIO_42); also elsewhere on the board
/LORA_CS: MCU_1.40 (GPIO_40); also elsewhere on the board
/LORA_DIO1: MCU_1.41 (GPIO_41); also elsewhere on the board
/LORA_MISO: MCU_1.34 (GPIO_34); also elsewhere on the board
/LORA_MOSI: MCU_1.35 (GPIO_35); also elsewhere on the board
/LORA_RF_SW: MCU_1.38 (GPIO_38); also elsewhere on the board
/LORA_SCLK: MCU_1.1 (GPIO_1); also elsewhere on the board
/MCU_NINA_B306/N_RST: J1.06, S1.1
/MCU_NINA_B306/SWD_CLK: J1.04, MCU_1.11 (SWDCLK)
/MCU_NINA_B306/SWD_IO: J1.02, MCU_1.15 (SWDIO)
/PCLK: MCU_1.7 (GPIO_7); also elsewhere on the board
/RTC_CS: MCU_1.29 (NFC2/GPIO_29); also elsewhere on the board
/SIOC: MCU_1.2 (GPIO_2); also elsewhere on the board
/SIOD: MCU_1.3 (GPIO_3); also elsewhere on the board
/TFT_CS: MCU_1.24 (GPIO_24); also elsewhere on the board
/TFT_DC: MCU_1.25 (GPIO_25); also elsewhere on the board
/TFT_SDCS: MCU_1.27 (GPIO_27); also elsewhere on the board
/VSYNC: MCU_1.4 (GPIO_4); also elsewhere on the board
/XCLK: MCU_1.8 (SWO/TRACE_D0/GPIO_8); also elsewhere on the board
GND: D1.1, J1.03, J1.05, MCU_1.6 (GND), MCU_1.12 (GND__1), MCU_1.14 (GND__2), MCU_1.26 (GND__3), MCU_1.30 (GND__4), MCU_1.53 (GND__5), MCU_1.EAGP1 (EAGP), MCU_1.EAGP2 (EAGP__1), MCU_1.EAGP3 (EAGP__2), MCU_1.EAGP4 (EAGP__3), MCU_1.EGP1 (EGP), MCU_1.EGP2 (EGP__1), MCU_1.EGP3 (EGP__2), MCU_1.EGP4 (EGP__3), MCU_1.EGP5 (EGP__4), MCU_1.EGP6 (EGP__5), MCU_1.EGP7 (EGP__6), MCU_1.EGP8 (EGP__7), MCU_1.EGP9 (EGP__8), MCU_1.EGP10 (EGP__9), MCU_1.EGP11 (EGP__10), MCU_1.EGP12 (EGP__11), S1.2, S1.4, TP4.1; also elsewhere on the board
unnamed: D1.2, MCU_1.52 (QSPI_CLK/GPIO_52)
unnamed: MCU_1.19 (~RESET), S1.3

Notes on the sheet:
Exposed Antenna Ground Pin
Exposed Ground Pin
CMSIS-DAP Port

Board: 2 copper layers, 43 parts (0 on the bottom side), 54 nets, no tracks yet.

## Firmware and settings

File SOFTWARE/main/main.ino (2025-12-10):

/*
    Before starting, install following libraries:
        - adafruit_gfx
        - adafruit_st7735
        - arduino_hs300x
        - arduino_bmi270_bmm150
        - arduino_LPS22HB
        - ds3231

*/
#include <SPI.h>
#include <Adafruit_GFX.h>
#include <Adafruit_ST7735.h> // using 0.96" 160x80 tft display
#include <Arduino_HS300x.h>
#include <DS3231.h>
#include <time.h>

// Pinouts
#define CAM_D0 D0
#define CAM_D1 D1
#define CAM_D2 D2
#define CAM_D3 D3
#define CAM_D4 D4
#define CAM_D5 D5
#define CAM_D6 D6
#define CAM_D7 D7
#define CAM_VSYNC D8
#define CAM_XCLK D9 
#define CAM_HREF D10
#define TFT_DC A0
#define LORA_CS A1
#define LORA_RST A2
#define TFT_CS A3
#define CAM_SIOD A4
#define CAM_SIOC A5
#define RTC_CS A6
#define CAM_PCLK A7
#define UNUSED_PIN -1

#define DEBUG
#ifdef DEBUG
    #define DEBUG_PRINT(x) Serial.print(x)
    #define DEBUG_PRINTLN(x) Serial.println(x) 
#else
    #define DEBUG_PRINT(x) 
    #define DEBUG_PRINTLN(x) 
#endif

// tft screen
Adafruit_ST7735 tft = Adafruit_ST7735(TFT_CS, TFT_DC, UNUSED_PIN);

// DS3231 rtc
// RTClib myRTC;
// DateTime now = myRTC.now();

// temperature and humidity sensor
float old_temp = 0;
float old_hum = 0;

void showTemperatureHumidity(void){
    float temperature = HS300x.readTemperature();
    float humidity = HS300x.readHumidity();

    if (abs(old_temp - temperature) >= 0.5 || abs(old_hum - humidity) >= 1){
        DEBUG_PRINT("Temperature: ");
        DEBUG_PRINTLN(temperature);

        DEBUG_PRINT("Humidity: ");
        DEBUG_PRINTLN(humidity);
        DEBUG_PRINTLN(" %");

        delay(500);
    }
}

void drawText(char *text, uint16_t textColor, uint8_t xCursor, uint8_t yCursor){
    tft.setRotation(1);
    tft.setCursor(xCursor, yCursor);
    tft.setTextColor(textColor, ST7735_BLACK);
    tft.setTextWrap(true);
    tft.print(text);
}

void setup() {
    Serial.begin(11600);
    SPI.begin();

    if (!HS300x.begin()){
        DEBUG_PRINTLN("Failed to init HS300x!");
    } 

    // Camera Pins
    pinMode(CAM_SIOD, INPUT); // Serial ubterface data I/o
    pinMode(CAM_SIOC, INPUT); // Serial clock
    pinMode(CAM_D0, OUTPUT); 
    pinMode(CAM_D1, OUTPUT);
    pinMode(CAM_D2, OUTPUT);
    pinMode(CAM_D3, OUTPUT);
    pinMode(CAM_D4, OUTPUT);
    pinMode(CAM_D5, OUTPUT);
    pinMode(CAM_D6, OUTPUT);
    pinMode(CAM_D7, OUTPUT);
    pinMode(CAM_VSYNC, OUTPUT); // vertical sync output
    pinMode(CAM_HREF, OUTPUT); // href output
    pinMode(CAM_PCLK, OUTPUT); // pixel clock output
    pinMode(CAM_XCLK, OUTPUT); // system clock output


    // LoRa Module Pins
    pinMode(LORA_CS, OUTPUT);
    pinMode(LORA_RST, OUTPUT);

    // TFT Screen Pins
    pinMode(TFT_CS, OUTPUT);
    tft.initR(INITR_MINI160x80);
    tft.fillScreen(ST7735_BLACK);

    // RTC Pins
    pinMode(RTC_CS, OUTPUT);

    delay(3000);
    DEBUG_PRINTLN("Finished Setup...");
}

void loop(){
    Serial.println("1");
    //drawText("Hello World!", ST7735_WHITE, 0, 50);
    delay(1000);
    // // showTemperatureHumidity();
    Serial.println("2");

    // Serial.println(now.year(), DEC);
    Serial.println(3);
    // Serial.println("WHY ");
}

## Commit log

2025-09-19 Add readme.md
    [BQ24650RVAT.step, Power.kicad_sch, is-plant-okay.kicad_pcb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]
2025-09-19 add bq24650 schematic
    [BQ7791504PW.step, Power.kicad_sch]
2025-09-19 add bq77915 module
    [Power.kicad_sch]
2025-09-29 add BOM, add changes to MCU
    [mcu.kicad_sch]
2025-10-02 changed oled display
    [mcu.kicad_sch]
2025-10-07 add arduino code
2025-10-08 add pinout and bom alternative
2025-10-09 feat: added pins for mcu
    [mcu.kicad_sch]
2025-10-09 feat: added spi to bom, added pin out
2025-10-13 docs: add stages 0, 1a, 1b to readme
2025-10-30 feat: minor pin fixes, add camera moduel to schematic
    [is-plant-okay.kicad_sch, mcu.kicad_sch, sensors.kicad_sch]
2025-10-31 feat: add lora, rtc, coin cell, tft screen to schematic
    [is-plant-okay.kicad_sch, mcu.kicad_sch]
2025-11-27 feat: add pins to setup function
    [mcu.kicad_sch]
2025-12-10 feat: add schematic and footprints for ds3234 and ninab306
    [21-0042O_W20H2_MXM.step, CAMERA_0V7670.kicad_sch, DISPLAY_TFT.kicad_sch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]
2025-12-10 feat: add lora
    [LoRA_RADIO.kicad_sch, SX1276IMLTRT.step, USB_C_3-3V.kicad_sch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]
2025-12-11 feat: add coin cell footprint
    [BAT-HLD-003-SMT.step, RTC_DS3234.kicad_sch]
2025-12-13 feat: add header pins for tft and camera
    [10129381-918001BLF.step, CAMERA_0V7670.kicad_sch, DISPLAY_TFT.kicad_sch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]
2025-12-13 feat: add usb and esd protection device
    [LoRA_RADIO.kicad_sch, RTC_DS3234.kicad_sch, USB4085-GF-A.STEP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]
2025-12-13 feat: add ldo and power management IC
    [254TR.step, MCP73871-2CCI_ML.step, MCP73871.kicad_sch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]
2025-12-15 feat: add pins for mcu
    [CAMERA_0V7670.kicad_sch, DISPLAY_TFT.kicad_sch, LoRA_RADIO.kicad_sch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]
2025-12-16 feat: add pins for bootloader programmer
    [LoRA_RADIO.kicad_sch, MCU_NINA_B306.kicad_sch, RTC_DS3234.kicad_sch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]
2025-12-17 feat: finished schematics
    [CAMERA_0V7670.kicad_sch, DISPLAY_TFT.kicad_sch, LoRA_RADIO.kicad_sch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]
2025-12-17 feat: add resistor footprint
    [LoRA_RADIO.kicad_sch, MCP73871.kicad_sch, MCU_NINA_B306.kicad_sch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]
2025-12-18 feat: add remaining resistor, capacitor footprints
    [CL05B104KO5NNNC.step, CL31B105KBHNNNE.step, CRGCQ0805J470R.step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]

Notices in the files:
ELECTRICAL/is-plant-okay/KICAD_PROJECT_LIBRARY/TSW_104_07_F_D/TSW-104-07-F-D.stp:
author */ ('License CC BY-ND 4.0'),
